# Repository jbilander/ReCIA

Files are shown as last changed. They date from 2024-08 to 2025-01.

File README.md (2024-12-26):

# ReCIA
A drop in replacement CIA (8520) for old Amiga Computers

This is WORK IN PROGRESS. If you generate gerbers and order PCBs from this source you are doing so completely at your own risk!.

Current design is based on an intel/altera 10 Max FPGA but this is mostly so we can signal tap and record how a real 8520 behaves.
The oscillator on board is 10 MHz and the PLL on the Max 10 can take this clock and make a perfect 28.375 MHz or a 28.636 MHz clock signal which will be nice to base the logic on instead of the E-CLK.

The final design will probably target a `LCMXO2-640HC-4SG48C` FPGA or a microcontroller such as `AVR128DA64` or a `RP2350`.

When the DIP-version is functional a PLCC-version (for big box Amigas) can be made.

***

<a href="images/ReCIA-Max10_pic1.png">
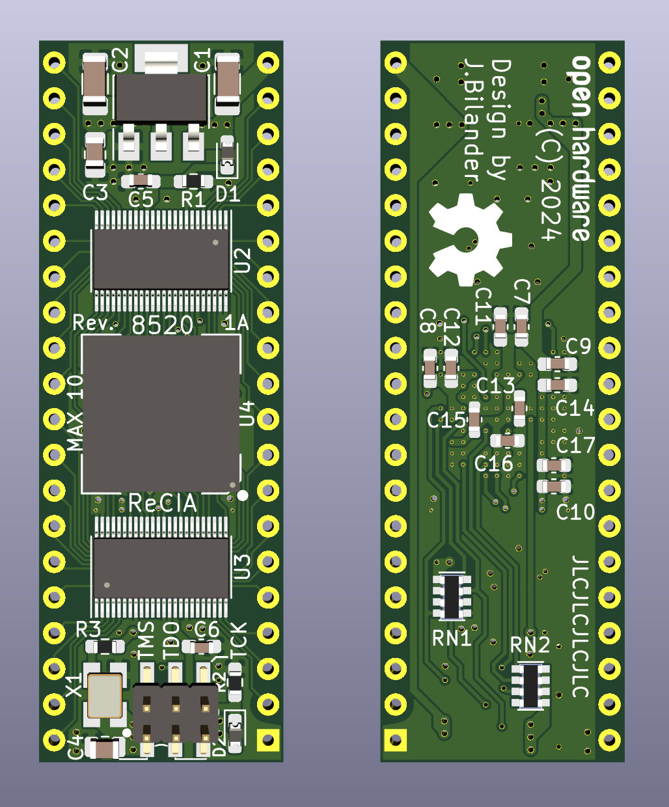
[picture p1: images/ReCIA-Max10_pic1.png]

</a>
<br />
<a href="images/ReCIA-Max10_pic2.jpg">
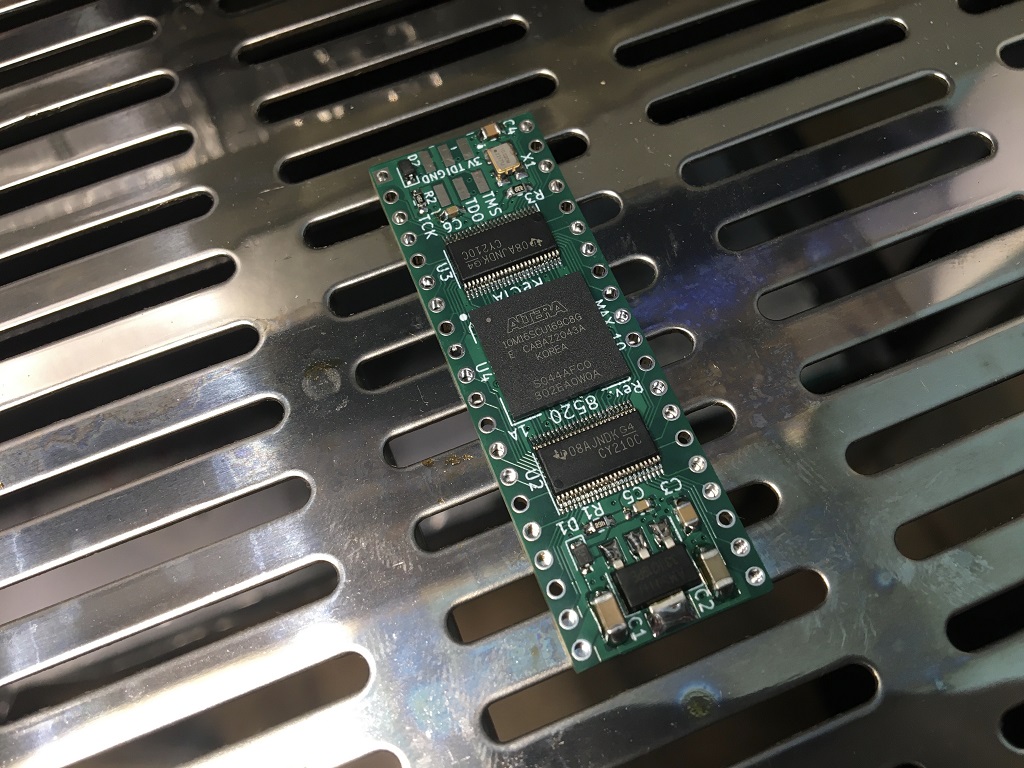
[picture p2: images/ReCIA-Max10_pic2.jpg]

</a>
<a href="images/ReCIA-Max10_pic3.jpg">
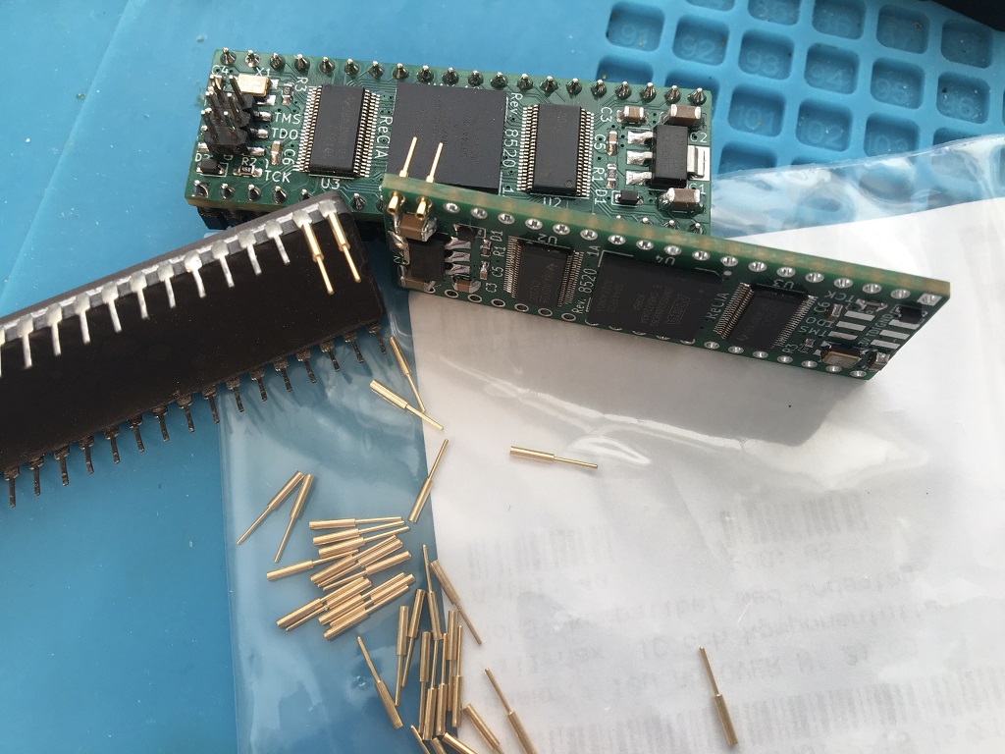
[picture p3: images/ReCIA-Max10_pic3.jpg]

</a>
<a href="images/ReCIA-Max10_pic4.jpg">
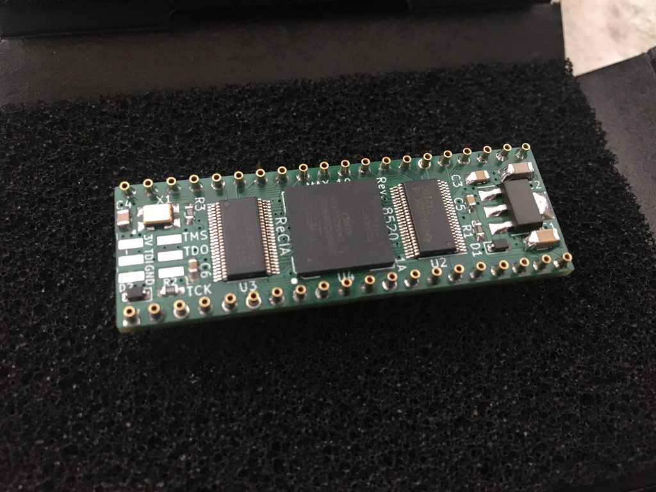
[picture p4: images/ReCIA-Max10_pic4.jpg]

</a>
<br />
<a href="images/ReCIA-Max10_pic5.jpg">
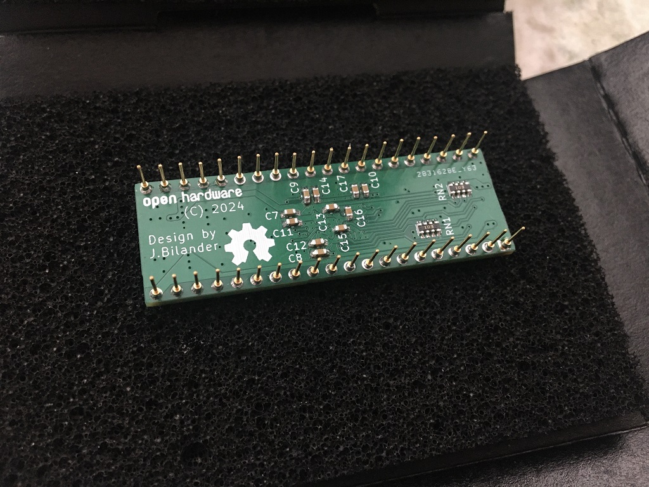
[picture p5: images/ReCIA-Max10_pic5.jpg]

</a>
<a href="images/ReCIA-Max10_pic6.jpg">
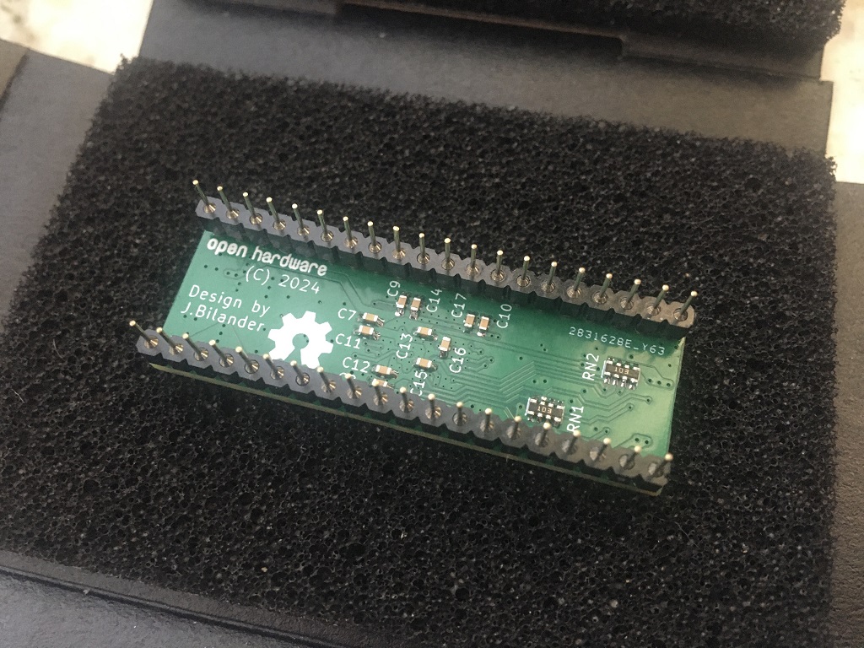
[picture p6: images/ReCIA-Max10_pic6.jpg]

</a>
<a href="images/ReCIA-Max10_pic7.jpg">
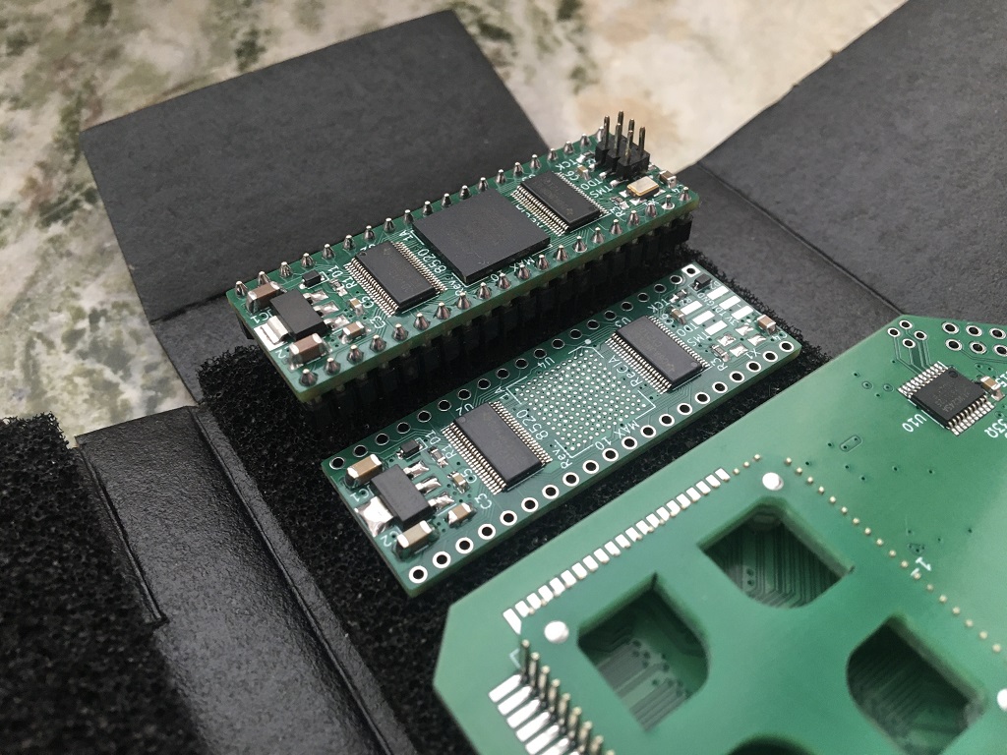
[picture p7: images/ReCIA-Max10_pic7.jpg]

</a>
<br />
<a href="images/ReCIA-Max10_pic8.jpg">
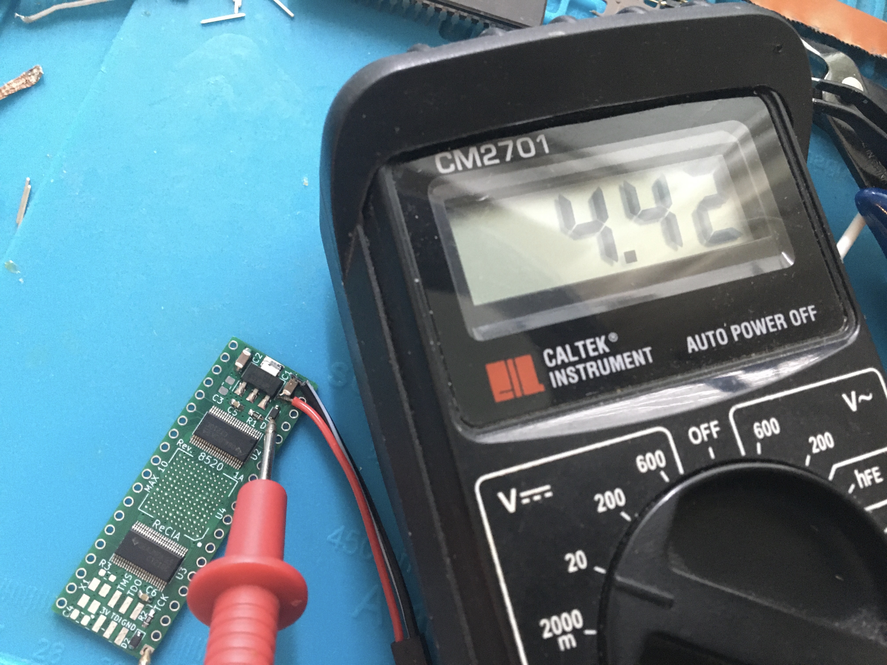
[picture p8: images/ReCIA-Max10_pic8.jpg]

</a>
<a href="images/ReCIA-Max10_pic9.jpg">
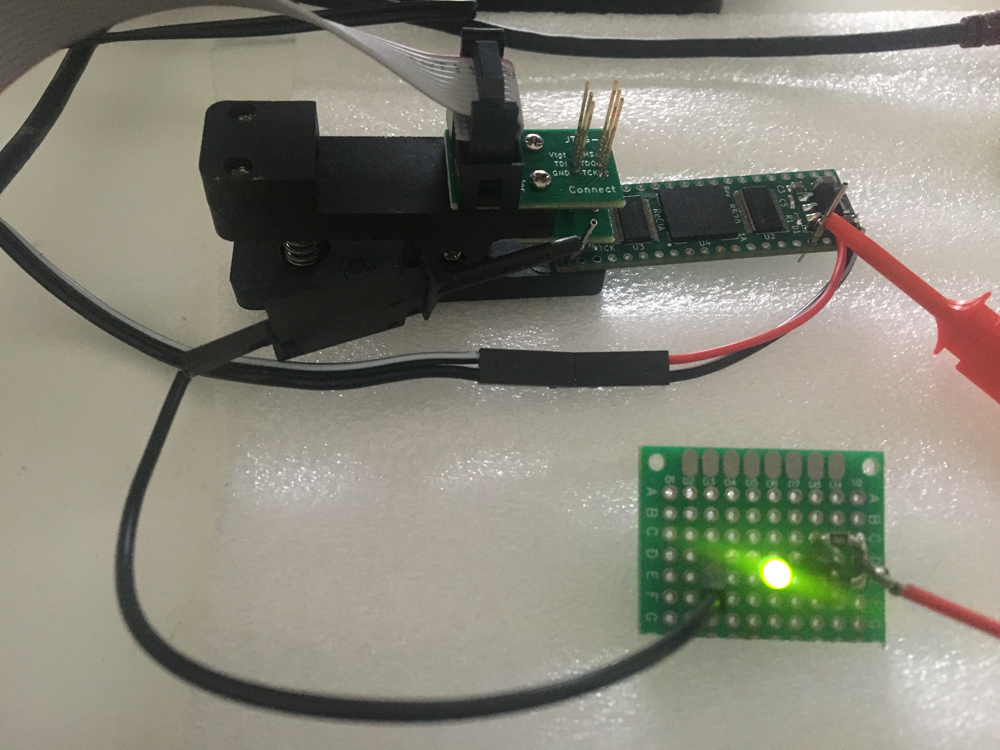
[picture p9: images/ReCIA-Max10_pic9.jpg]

</a>

***

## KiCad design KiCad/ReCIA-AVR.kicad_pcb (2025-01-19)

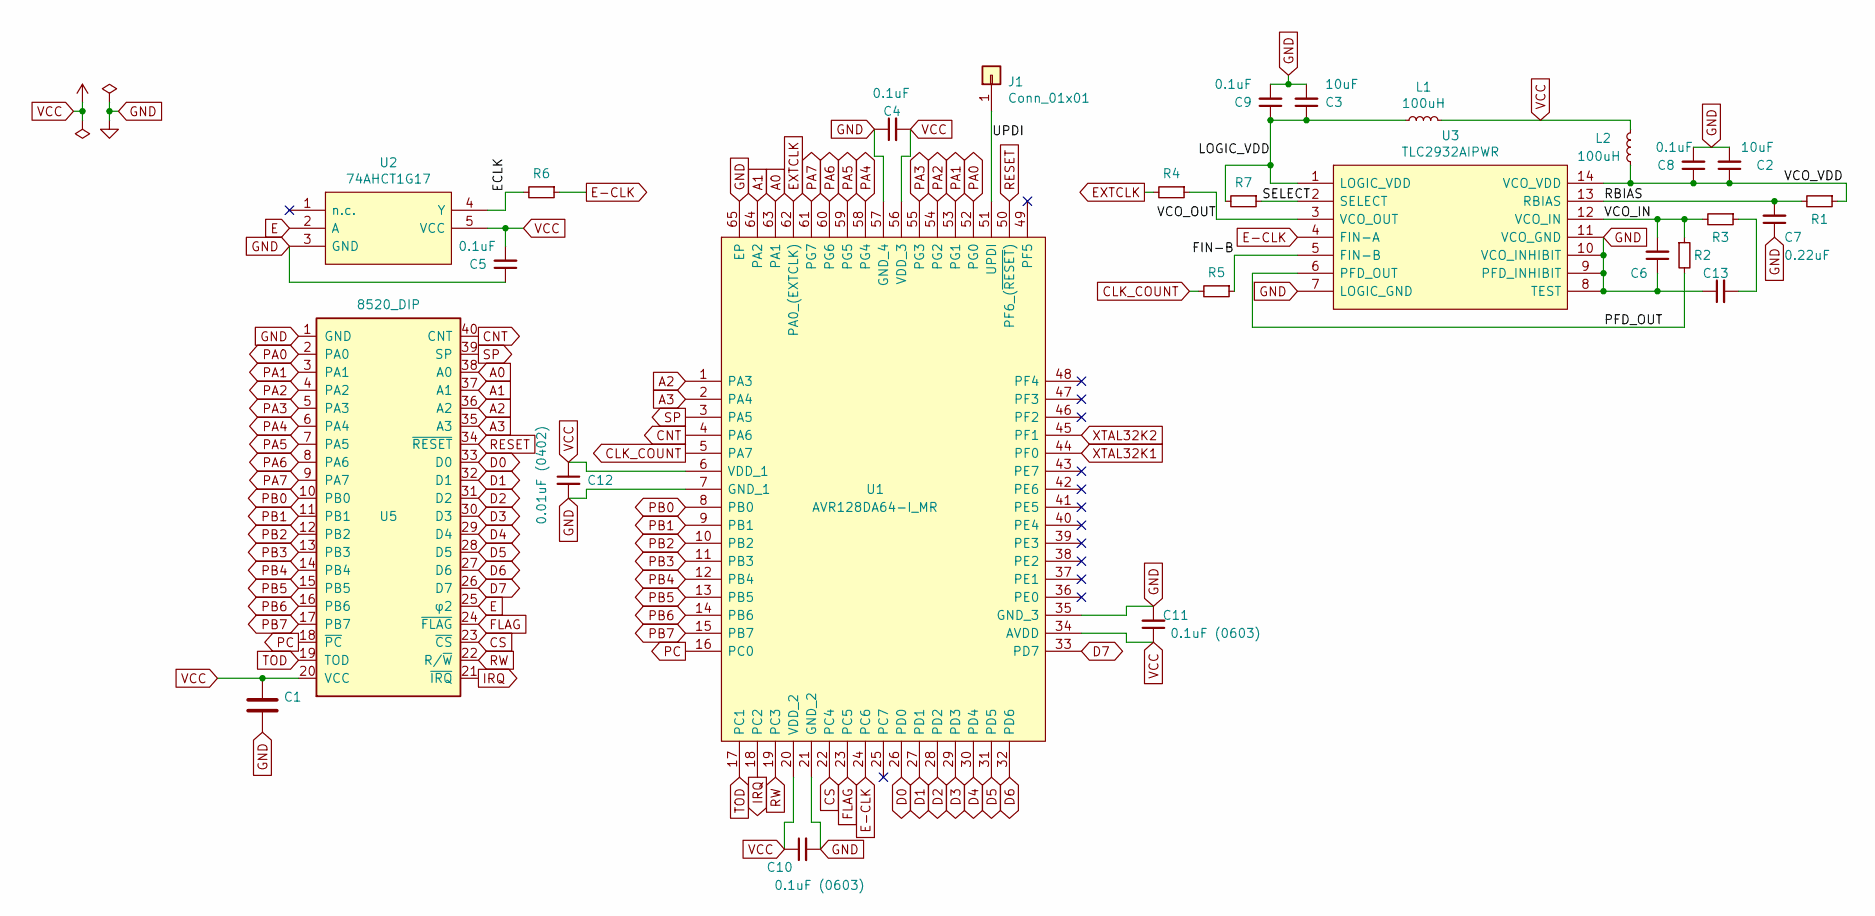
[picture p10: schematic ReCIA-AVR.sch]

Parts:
C1: C; C_1206_3216Metric_Pad1.33x1.80mm_HandSolder
C2, C3: 10uF; C_1206_3216Metric_Pad1.33x1.80mm_HandSolder
C4, C5, C6, C8, C9, C13: 0.1uF; C_0603_1608Metric_Pad1.08x0.95mm_HandSolder
C7: 0.22uF; C_0603_1608Metric_Pad1.08x0.95mm_HandSolder
C10, C11: 0.1uF (0603); C_0603_1608Metric_Pad1.08x0.95mm_HandSolder
C12: 0.01uF (0402); C_0402_1005Metric
J1: Conn_01x01; PinHeader_1x01_P2.54mm_Vertical
L1, L2: 100uH; L_0805_2012Metric_Pad1.15x1.40mm_HandSolder
R1: 3k3; R_0603_1608Metric_Pad0.98x0.95mm_HandSolder
R2, R3, R4, R5, R6: 33; R_0603_1608Metric_Pad0.98x0.95mm_HandSolder
R7: 10k; R_0603_1608Metric_Pad0.98x0.95mm_HandSolder
U1: AVR128DA64-I_MR; QFN-64-1EP_9x9mm_P0.5mm_EP7.15x7.15mm_ThermalVias
U2: 74AHCT1G17; SOT95P275X110-5N
U3: TLC2932AIPWR; TSSOP-14_4.4x5mm_P0.65mm
U5: 8520_DIP; DIP-40_W15.24mm

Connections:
/ECLK: R6.2, U2.4 (Y)
/FIN-B: R5.1, U3.5 (FIN-B)
/LOGIC_VDD: C3.1, C9.1, L1.1, R7.2, U3.1 (LOGIC_VDD)
/PFD_OUT: R2.2, U3.6 (PFD_OUT)
/RBIAS: C7.2, R1.2, U3.13 (RBIAS)
/SELECT: R7.1, U3.2 (SELECT)
/UPDI: J1.1, U1.51 (UPDI)
/VCO_IN: C6.2, R2.1, R3.2, U3.12 (VCO_IN)
/VCO_OUT: R4.1, U3.3 (VCO_OUT)
/VCO_VDD: C2.1, C8.1, L2.1, R1.1, U3.14 (VCO_VDD)
A0: U1.63 (PA1), U5.38 (A0)
A1: U1.64 (PA2), U5.37 (A1)
A2: U1.1 (PA3), U5.36 (A2)
A3: U1.2 (PA4), U5.35 (A3)
CLK_COUNT: R5.2, U1.5 (PA7)
CNT: U1.4 (PA6), U5.40 (CNT)
CS: U1.22 (PC4), U5.23 (~CS)
D0: U1.26 (PD0), U5.33 (D0)
D1: U1.27 (PD1), U5.32 (D1)
D2: U1.28 (PD2), U5.31 (D2)
D3: U1.29 (PD3), U5.30 (D3)
D4: U1.30 (PD4), U5.29 (D4)
D5: U1.31 (PD5), U5.28 (D5)
D6: U1.32 (PD6), U5.27 (D6)
D7: U1.33 (PD7), U5.26 (D7)
E: U2.2 (A), U5.25 (φ2)
E-CLK: R6.1, U1.24 (PC6), U3.4 (FIN-A)
EXTCLK: R4.2, U1.62 (PA0_(EXTCLK))
FLAG: U1.23 (PC5), U5.24 (~FLAG)
GND: C1.2, C2.2, C3.2, C4.1, C5.1, C6.1, C7.1, C8.2, C9.2, C10.2, C11.2, C12.2, C13.1, U1.7 (GND_1), U1.21 (GND_2), U1.35 (GND_3), U1.57 (GND_4), U1.65 (EP), U2.3 (GND), U3.7 (LOGIC_GND), U3.8 (TEST), U3.9 (PFD_INHIBIT), U3.10 (VCO_INHIBIT), U3.11 (VCO_GND), U5.1 (GND)
IRQ: U1.18 (PC2), U5.21 (~IRQ)
unnamed: C13.2, R3.1
PA0: U1.52 (PG0), U5.2 (PA0)
PA1: U1.53 (PG1), U5.3 (PA1)
PA2: U1.54 (PG2), U5.4 (PA2)
PA3: U1.55 (PG3), U5.5 (PA3)
PA4: U1.58 (PG4), U5.6 (PA4)
PA5: U1.59 (PG5), U5.7 (PA5)
PA6: U1.60 (PG6), U5.8 (PA6)
PA7: U1.61 (PG7), U5.9 (PA7)
PB0: U1.8 (PB0), U5.10 (PB0)
PB1: U1.9 (PB1), U5.11 (PB1)
PB2: U1.10 (PB2), U5.12 (PB2)
PB3: U1.11 (PB3), U5.13 (PB3)
PB4: U1.12 (PB4), U5.14 (PB4)
PB5: U1.13 (PB5), U5.15 (PB5)
PB6: U1.14 (PB6), U5.16 (PB6)
PB7: U1.15 (PB7), U5.17 (PB7)
PC: U1.16 (PC0), U5.18 (~PC)
RESET: U1.50 (PF6_(~RESET)), U5.34 (~RESET)
RW: U1.19 (PC3), U5.22 (R/~W)
SP: U1.3 (PA5), U5.39 (SP)
TOD: U1.17 (PC1), U5.19 (TOD)
VCC: C1.1, C4.2, C5.2, C10.1, C11.1, C12.1, L1.2, L2.2, U1.6 (VDD_1), U1.20 (VDD_2), U1.34 (AVDD), U1.56 (VDD_3), U2.5 (VCC), U5.20 (VCC)
XTAL32K1: U1.44 (PF0)
XTAL32K2: U1.45 (PF1)

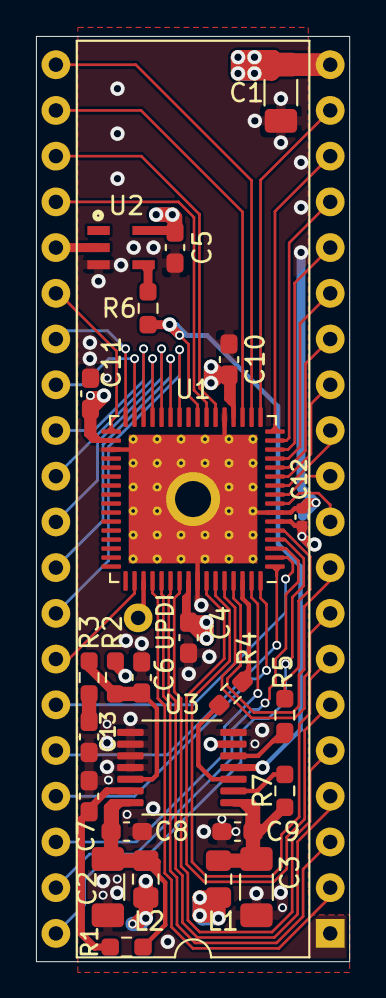
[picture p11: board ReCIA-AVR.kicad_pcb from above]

Board: 4 copper layers, 17.4 x 51.4 mm, 27 parts (0 on the bottom side), 54 nets.

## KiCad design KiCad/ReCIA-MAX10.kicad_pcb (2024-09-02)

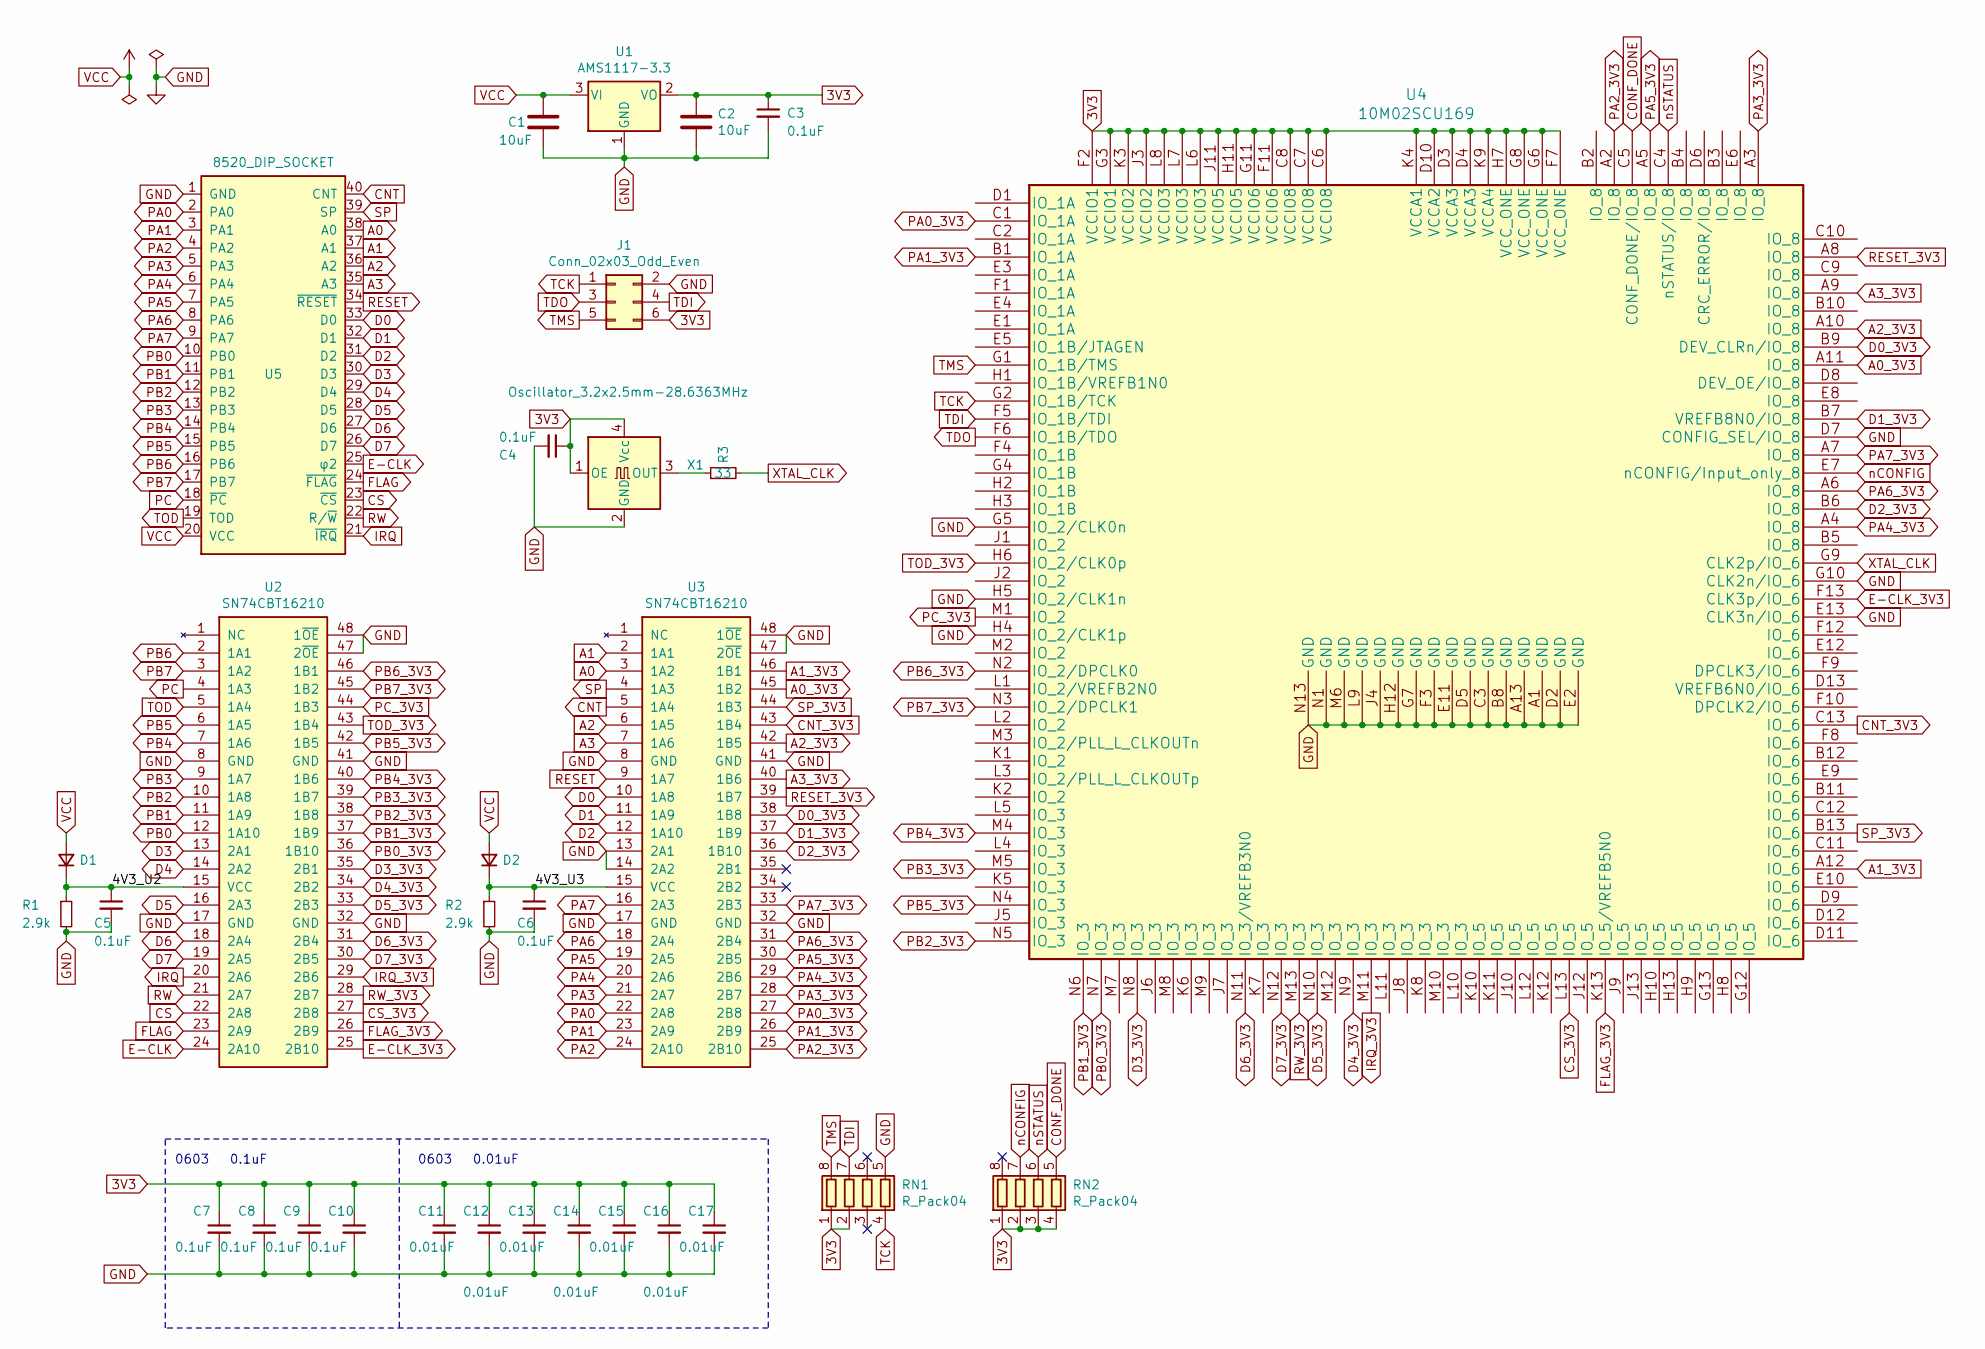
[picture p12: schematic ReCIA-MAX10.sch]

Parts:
C1, C2: 10uF; C_1206_3216Metric_Pad1.33x1.80mm_HandSolder
C3: 0.1uF; C_0805_2012Metric_Pad1.18x1.45mm_HandSolder
C4: 0.1uF; C_0805_2012Metric
C5, C6, C7, C8, C9: 0.1uF; C_0603_1608Metric_Pad1.08x0.95mm_HandSolder
C10: 0.1uF; C_0603_1608Metric
C11, C12, C13, C14, C15: 0.01uF; C_0603_1608Metric_Pad1.08x0.95mm_HandSolder
C16, C17: 0.01uF; C_0603_1608Metric
D1, D2: D_Small; D_0603_1608Metric_Pad1.05x0.95mm_HandSolder
J1: Conn_02x03_Odd_Even; PinHeader_2x03_P2.00mm_Vertical_SMD
R1, R2: 2.9k; R_0603_1608Metric_Pad0.98x0.95mm_HandSolder
R3: 33; R_0603_1608Metric_Pad0.98x0.95mm_HandSolder
RN1, RN2: R_Pack04; RESCAF80P320X160X60-8N
U1: AMS1117-3.3; SOT-223-3_TabPin2
U2, U3: SN74CBT16210; TSSOP-48_4.4x9.7mm_P0.4mm
U4: 10M02SCU169; BGA-169_11.0x11.0mm_Layout13x13_P0.8mm_Ball0.5mm_Pad0.35mm_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
U5: 8520_DIP_SOCKET; DIP-40_W15.24mm
X1: Oscillator_3.2x2.5mm-28.6363MHz; Oscillator_SMD_SeikoEpson_SG8002CE-4Pin_3.2x2.5mm

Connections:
3V3: C2.1, C3.1, C4.1, C7.1, C8.1, C9.1, C10.1, C11.1, C12.1, C13.1, C14.1, C15.1, C16.1, C17.1, J1.6, RN1.1 (R1.1), RN1.2 (R2.1), RN2.1 (R1.1), RN2.2 (R2.1), RN2.3 (R3.1), RN2.4 (R4.1), U1.2 (VO), U4.C6 (VCCIO8), U4.C7 (VCCIO8), U4.C8 (VCCIO8), U4.D3 (VCCA3), U4.D4 (VCCA3), U4.D10 (VCCA2), U4.F2 (VCCIO1), U4.F7 (VCC_ONE), U4.F11 (VCCIO6), U4.G3 (VCCIO1), U4.G6 (VCC_ONE), U4.G8 (VCC_ONE), U4.G11 (VCCIO6), U4.H7 (VCC_ONE), U4.H11 (VCCIO5), U4.J3 (VCCIO2), U4.J11 (VCCIO5), U4.K3 (VCCIO2), U4.K4 (VCCA1), U4.K9 (VCCA4), U4.L6 (VCCIO3), U4.L7 (VCCIO3), U4.L8 (VCCIO3), X1.1 (OE), X1.4 (Vcc)
/4V3_U2: C5.1, D1.1 (K), R1.1, U2.15 (VCC)
/4V3_U3: C6.1, D2.1 (K), R2.1, U3.15 (VCC)
A0: U3.3 (1A2), U5.38 (A0)
A0_3V3: U3.45 (1B2), U4.A11 (IO_8)
A1: U3.2 (1A1), U5.37 (A1)
A1_3V3: U3.46 (1B1), U4.A12 (IO_6)
A2: U3.6 (1A5), U5.36 (A2)
A2_3V3: U3.42 (1B5), U4.A10 (IO_8)
A3: U3.7 (1A6), U5.35 (A3)
A3_3V3: U3.40 (1B6), U4.A9 (IO_8)
CNT: U3.5 (1A4), U5.40 (CNT)
CNT_3V3: U3.43 (1B4), U4.C13 (IO_6)
CONF_DONE: RN2.5 (R4.2), U4.C5 (CONF_DONE/IO_8)
CS: U2.22 (2A8), U5.23 (~CS)
CS_3V3: U2.27 (2B8), U4.L13 (IO_5)
D0: U3.10 (1A8), U5.33 (D0)
D0_3V3: U3.38 (1B8), U4.B9 (DEV_CLRn/IO_8)
D1: U3.11 (1A9), U5.32 (D1)
D1_3V3: U3.37 (1B9), U4.B7 (VREFB8N0/IO_8)
D2: U3.12 (1A10), U5.31 (D2)
D2_3V3: U3.36 (1B10), U4.B6 (IO_8)
D3: U2.13 (2A1), U5.30 (D3)
D3_3V3: U2.35 (2B1), U4.N8 (IO_3)
D4: U2.14 (2A2), U5.29 (D4)
D4_3V3: U2.34 (2B2), U4.N9 (IO_3)
D5: U2.16 (2A3), U5.28 (D5)
D5_3V3: U2.33 (2B3), U4.N10 (IO_3)
D6: U2.18 (2A4), U5.27 (D6)
D6_3V3: U2.31 (2B4), U4.N11 (IO_3/VREFB3N0)
D7: U2.19 (2A5), U5.26 (D7)
D7_3V3: U2.30 (2B5), U4.N12 (IO_3)
E-CLK: U2.24 (2A10), U5.25 (φ2)
E-CLK_3V3: U2.25 (2B10), U4.F13 (CLK3p/IO_6)
FLAG: U2.23 (2A9), U5.24 (~FLAG)
FLAG_3V3: U2.26 (2B9), U4.K13 (IO_5/VREFB5N0)
GND: C1.2, C2.2, C3.2, C4.2, C5.2, C6.2, C7.2, C8.2, C9.2, C10.2, C11.2, C12.2, C13.2, C14.2, C15.2, C16.2, C17.2, J1.2, R1.2, R2.2, RN1.5 (R4.2), U1.1 (GND), U2.8 (GND), U2.17 (GND), U2.32 (GND), U2.41 (GND), U2.47 (2~OE), U2.48 (1~OE), U3.8 (GND), U3.13 (2A1), U3.14 (2A2), U3.17 (GND), U3.32 (GND), U3.41 (GND), U3.47 (2~OE), U3.48 (1~OE), U4.A1 (GND), U4.A13 (GND), U4.B8 (GND), U4.C3 (GND), U4.D2 (GND), U4.D5 (GND), U4.D7 (CONFIG_SEL/IO_8), U4.E2 (GND), U4.E11 (GND), U4.E13 (CLK3n/IO_6), U4.F3 (GND), U4.G5 (IO_2/CLK0n), U4.G7 (GND), U4.G10 (CLK2n/IO_6), U4.H4 (IO_2/CLK1p), U4.H5 (IO_2/CLK1n), U4.H12 (GND), U4.J4 (GND), U4.L9 (GND), U4.M6 (GND), U4.N1 (GND), U4.N13 (GND), U5.1 (GND), X1.2 (GND)
IRQ: U2.20 (2A6), U5.21 (~IRQ)
IRQ_3V3: U2.29 (2B6), U4.M11 (IO_3)
unnamed: R3.1, X1.3 (OUT)
PA0: U3.22 (2A8), U5.2 (PA0)
PA0_3V3: U3.27 (2B8), U4.C1 (IO_1A)
PA1: U3.23 (2A9), U5.3 (PA1)
PA1_3V3: U3.26 (2B9), U4.B1 (IO_1A)
PA2: U3.24 (2A10), U5.4 (PA2)
PA2_3V3: U3.25 (2B10), U4.A2 (IO_8)
PA3: U3.21 (2A7), U5.5 (PA3)
PA3_3V3: U3.28 (2B7), U4.A3 (IO_8)
PA4: U3.20 (2A6), U5.6 (PA4)
PA4_3V3: U3.29 (2B6), U4.A4 (IO_8)
PA5: U3.19 (2A5), U5.7 (PA5)
PA5_3V3: U3.30 (2B5), U4.A5 (IO_8)
PA6: U3.18 (2A4), U5.8 (PA6)
PA6_3V3: U3.31 (2B4), U4.A6 (IO_8)
PA7: U3.16 (2A3), U5.9 (PA7)
PA7_3V3: U3.33 (2B3), U4.A7 (IO_8)
PB0: U2.12 (1A10), U5.10 (PB0)
PB0_3V3: U2.36 (1B10), U4.N7 (IO_3)
PB1: U2.11 (1A9), U5.11 (PB1)
PB1_3V3: U2.37 (1B9), U4.N6 (IO_3)
PB2: U2.10 (1A8), U5.12 (PB2)
PB2_3V3: U2.38 (1B8), U4.N5 (IO_3)
PB3: U2.9 (1A7), U5.13 (PB3)
PB3_3V3: U2.39 (1B7), U4.M5 (IO_3)
PB4: U2.7 (1A6), U5.14 (PB4)
PB4_3V3: U2.40 (1B6), U4.M4 (IO_3)
PB5: U2.6 (1A5), U5.15 (PB5)
PB5_3V3: U2.42 (1B5), U4.N4 (IO_3)
PB6: U2.2 (1A1), U5.16 (PB6)
PB6_3V3: U2.46 (1B1), U4.N2 (IO_2/DPCLK0)
PB7: U2.3 (1A2), U5.17 (PB7)
PB7_3V3: U2.45 (1B2), U4.N3 (IO_2/DPCLK1)
PC: U2.4 (1A3), U5.18 (~PC)
PC_3V3: U2.44 (1B3), U4.M1 (IO_2)
RESET: U3.9 (1A7), U5.34 (~RESET)
RESET_3V3: U3.39 (1B7), U4.A8 (IO_8)
RW: U2.21 (2A7), U5.22 (R/~W)
RW_3V3: U2.28 (2B7), U4.M13 (IO_3)
SP: U3.4 (1A3), U5.39 (SP)
SP_3V3: U3.44 (1B3), U4.B13 (IO_6)
TCK: J1.1, RN1.4 (R4.1), U4.G2 (IO_1B/TCK)
TDI: J1.4, RN1.7 (R2.2), U4.F5 (IO_1B/TDI)
TDO: J1.3, U4.F6 (IO_1B/TDO)
TMS: J1.5, RN1.8 (R1.2), U4.G1 (IO_1B/TMS)
TOD: U2.5 (1A4), U5.19 (TOD)
TOD_3V3: U2.43 (1B4), U4.H6 (IO_2/CLK0p)
VCC: C1.1, D1.2 (A), D2.2 (A), U1.3 (VI), U5.20 (VCC)
XTAL_CLK: R3.2, U4.G9 (CLK2p/IO_6)
nCONFIG: RN2.7 (R2.2), U4.E7 (nCONFIG/Input_only_8)
nSTATUS: RN2.6 (R3.2), U4.C4 (nSTATUS/IO_8)

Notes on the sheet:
0603 0.1uF
0603 0.01uF

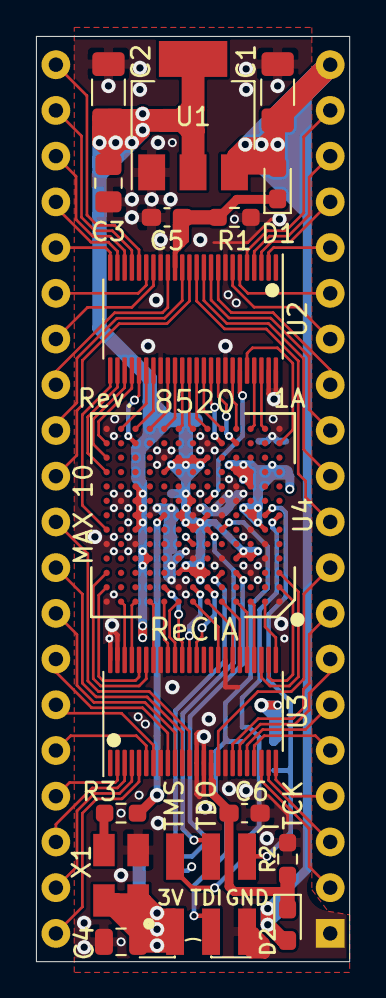
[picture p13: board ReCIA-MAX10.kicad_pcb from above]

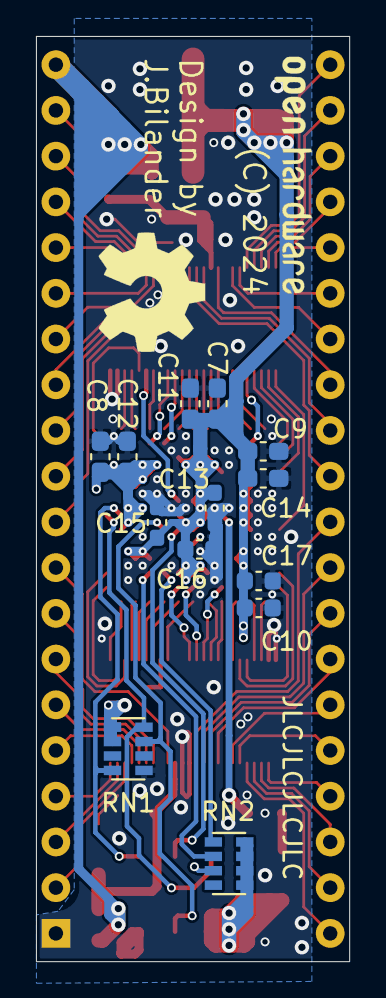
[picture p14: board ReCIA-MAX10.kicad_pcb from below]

Board: 4 copper layers, 17.4 x 51.4 mm, 31 parts (13 on the bottom side), 90 nets.

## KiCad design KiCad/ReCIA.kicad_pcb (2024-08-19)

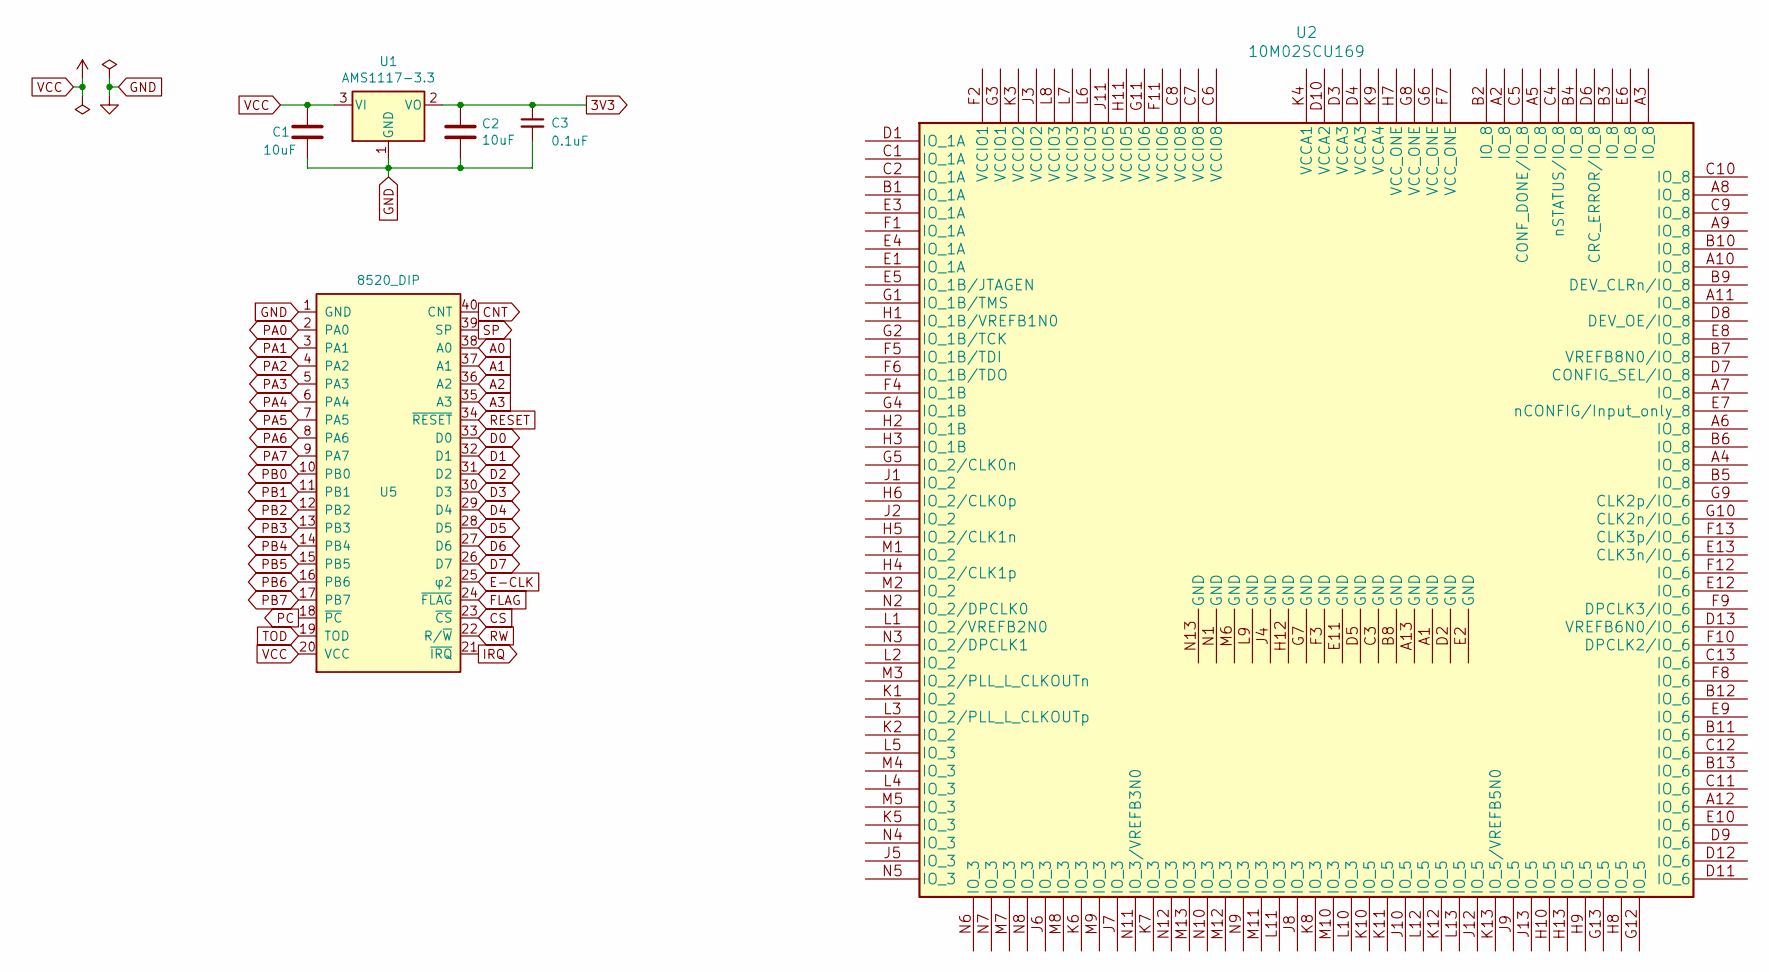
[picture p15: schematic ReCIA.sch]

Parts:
C1, C2: 10uF; C_1206_3216Metric_Pad1.33x1.80mm_HandSolder
C3: 0.1uF; C_0805_2012Metric_Pad1.18x1.45mm_HandSolder
U1: AMS1117-3.3; SOT-223-3_TabPin2
U2: 10M02SCU169; BGA-169_11.0x11.0mm_Layout13x13_P0.8mm_Ball0.5mm_Pad0.35mm_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
U5: 8520_DIP; DIP-40_W15.24mm

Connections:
3V3: C2.1, C3.1, U1.2 (VO)
A0: U5.38 (A0)
A1: U5.37 (A1)
A2: U5.36 (A2)
A3: U5.35 (A3)
CNT: U5.40 (CNT)
CS: U5.23 (~CS)
D0: U5.33 (D0)
D1: U5.32 (D1)
D2: U5.31 (D2)
D3: U5.30 (D3)
D4: U5.29 (D4)
D5: U5.28 (D5)
D6: U5.27 (D6)
D7: U5.26 (D7)
E-CLK: U5.25 (φ2)
FLAG: U5.24 (~FLAG)
GND: C1.2, C2.2, C3.2, U1.1 (GND), U5.1 (GND)
IRQ: U5.21 (~IRQ)
PA0: U5.2 (PA0)
PA1: U5.3 (PA1)
PA2: U5.4 (PA2)
PA3: U5.5 (PA3)
PA4: U5.6 (PA4)
PA5: U5.7 (PA5)
PA6: U5.8 (PA6)
PA7: U5.9 (PA7)
PB0: U5.10 (PB0)
PB1: U5.11 (PB1)
PB2: U5.12 (PB2)
PB3: U5.13 (PB3)
PB4: U5.14 (PB4)
PB5: U5.15 (PB5)
PB6: U5.16 (PB6)
PB7: U5.17 (PB7)
PC: U5.18 (~PC)
RESET: U5.34 (~RESET)
RW: U5.22 (R/~W)
SP: U5.39 (SP)
TOD: U5.19 (TOD)
VCC: C1.1, U1.3 (VI), U5.20 (VCC)

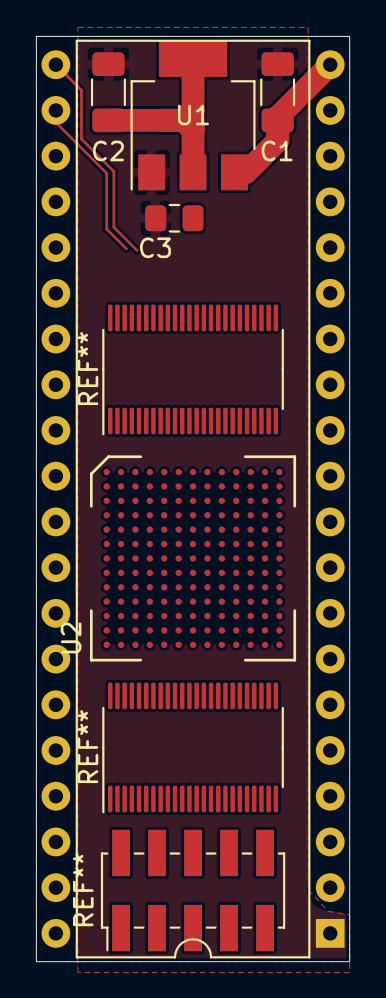
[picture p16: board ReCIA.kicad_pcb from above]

Board: 4 copper layers, 17.4 x 51.4 mm, 6 parts (0 on the bottom side), 3 nets.

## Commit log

2024-08-15 Add KiCad files
    [ReCIA.kicad_pcb, ReCIA.sch]
2024-08-15 Changed to four layers and fixed clearance and default settings for traces and vias etc
    [ReCIA.kicad_pcb]
2024-08-15 Add nets
    [ReCIA.kicad_pcb, ReCIA.sch]
2024-08-16 Added a 3.3V LDO Voltage Regulator
    [ReCIA.kicad_pcb, ReCIA.sch]
2024-08-19 Add footprint
2024-08-19 Add 10 Max FPGA
    [ReCIA.kicad_pcb, ReCIA.sch]
2024-08-21 Add KiCad files for AVR-version
    [ReCIA-AVR.kicad_pcb, ReCIA-AVR.sch]
2024-08-21 Add QFN-80 footprint
2024-08-21 Add KiCad files for Max10 version
    [ReCIA-MAX10.kicad_pcb, ReCIA-MAX10.sch]
2024-08-21 Add KiCad lib for Max10 version
2024-08-26 Add FET bus-switch level shifters SN74CBT16210
    [ReCIA-MAX10.kicad_pcb, ReCIA-MAX10.sch]
2024-08-26 Add JTAG-header
    [ReCIA-MAX10.kicad_pcb, ReCIA-MAX10.sch]
2024-08-27 more routing and pin assignment
    [ReCIA-MAX10.kicad_pcb, ReCIA-MAX10.sch]
2024-08-27 routing JTAG plus more routing of power to BGA chip
    [ReCIA-MAX10.kicad_pcb, ReCIA-MAX10.sch]
2024-08-27 add XTAL to design
    [ReCIA-MAX10.kicad_pcb, ReCIA-MAX10.sch]
2024-08-27 add XTAL step file to 3D Setting for X1
    [ReCIA-MAX10.kicad_pcb]
2024-08-27 add 15 mil trace
2024-08-27 re-routed XTAL trace with 15 mil trace
    [ReCIA-MAX10.kicad_pcb]
2024-08-27 more routing, pin assignments and silkscreen fixes
    [ReCIA-MAX10.kicad_pcb, ReCIA-MAX10.sch]
2024-08-28 more pin assignments and routing
    [ReCIA-MAX10.kicad_pcb, ReCIA-MAX10.sch]
2024-08-28 more power routing, vias and silkscreen fixes
    [ReCIA-MAX10.kicad_pcb]
2024-08-28 Changed to minimum width to 0.14 mm for front F.Cu zone and solid pad connection to zone for BGA-footprint.
    [ReCIA-MAX10.kicad_pcb]
2024-08-28 Silkscreen fixes, add dot indicator for pin 1 on U2,U3,U4
    [ReCIA-MAX10.kicad_pcb]
2024-08-28 Add pin assignment and routing for D0,D1,D2 to the FPGA
    [ReCIA-MAX10.kicad_pcb, ReCIA-MAX10.sch]
2024-08-29 Add decoupling caps for FPGA-chip
    [ReCIA-MAX10.kicad_pcb, ReCIA-MAX10.sch]
2024-08-30 Add more decoupling caps for FPGA-chip
    [ReCIA-MAX10.kicad_pcb, ReCIA-MAX10.sch]
2024-08-30 Assign GND to CONFIG_SEL pad
    [ReCIA-MAX10.kicad_pcb, ReCIA-MAX10.sch]
2024-08-30 Add nCONFIG signal
    [ReCIA-MAX10.kicad_pcb, ReCIA-MAX10.sch]
2024-08-30 Add nSTATUS signal
    [ReCIA-MAX10.kicad_pcb, ReCIA-MAX10.sch]
2024-08-30 Add CONF_DONE signal
    [ReCIA-MAX10.kicad_pcb, ReCIA-MAX10.sch]
2024-08-31 add 3d model for resistor pack
2024-08-31 add footprint for resistor pack
2024-08-31 Add 10k resistor pack RN1 and assign pull-ups for TMS, TDI and pull-down for TCK
    [ReCIA-MAX10.kicad_pcb, ReCIA-MAX10.sch]
2024-08-31 Add 10k resistor pack RN2 with pull-ups for CONF_DONE, nSTATUS, nCONFIG
    [ReCIA-MAX10.kicad_pcb, ReCIA-MAX10.sch]
2024-09-01 small fix 3V3-routing
    [ReCIA-MAX10.kicad_pcb]
2024-09-02 Assign H4,H5 pad to GND
    [ReCIA-MAX10.kicad_pcb, ReCIA-MAX10.sch]
2024-09-02 Add silkscreen texts
    [ReCIA-MAX10.kicad_pcb]
2024-09-02 corrected smalles via size to 0.45mm/0.2mm
    [ReCIA-MAX10.kicad_pcb]
2024-12-29 Pin assignment of A0-A3, SP, CNT signals for the AVR-version and more routing done
    [ReCIA-AVR.kicad_pcb, ReCIA-AVR.sch]
2025-01-05 Add a 74AHCT1G17 - Single Schmitt trigger buffer for the E-CLK on the AVR version
    [ReCIA-AVR.kicad_pcb, ReCIA-AVR.sch]
2025-01-05 Add decoupling cap for 74AHCT1G17 on the AVR version
    [ReCIA-AVR.kicad_pcb, ReCIA-AVR.sch]
2025-01-05 Add a 33 Ohm damping resistor on the E-CLK buffer out line
    [ReCIA-AVR.kicad_pcb, ReCIA-AVR.sch]
2025-01-05 Add TLC2932AIPWR to the AVR version
    [ReCIA-AVR.kicad_pcb, ReCIA-AVR.sch]
2025-01-05 Add 10uF 1206 capacitor on VCC input for the AVR version
    [ReCIA-AVR.kicad_pcb, ReCIA-AVR.sch]
2025-01-12 Fixed placement of PLL-chip and added inductor and caps for power supply pins Logic VDD and VCO VDD for the AVR-version
    [ReCIA-AVR.kicad_pcb, ReCIA-AVR.sch]
2025-01-12 Add 33 Ohm damping resistor on EXTCLK-line
    [ReCIA-AVR.kicad_pcb, ReCIA-AVR.sch]
2025-01-12 Add net and resistor between PDF_OUT and VCO_IN for the AVR-version
    [ReCIA-AVR.kicad_pcb, ReCIA-AVR.sch]
2025-01-12 Add resistor and net for PLL FIN-B clk-count input signal from AVR pin 5 (PA7)
    [ReCIA-AVR.kicad_pcb, ReCIA-AVR.sch]
2025-01-12 Add 0.4 mm track width
    [ReCIA-AVR.kicad_pcb]
2025-01-12 Add pull-up resistor on SELECT-line and more placement and routing fixes
    [ReCIA-AVR.kicad_pcb, ReCIA-AVR.sch]
2025-01-14 Add 3.3k resistor and 0.22uF cap for the RBIAS-pin on the PLL
    [ReCIA-AVR.kicad_pcb, ReCIA-AVR.sch]
2025-01-14 Add cap for the VCO_IN-pin on the PLL
    [ReCIA-AVR.kicad_pcb, ReCIA-AVR.sch]
2025-01-16 Change from 0805 to 1206 size on C2 and C3
    [ReCIA-AVR.kicad_pcb, ReCIA-AVR.sch]
2025-01-16 Add resistor and cap on VCO_IN line
    [ReCIA-AVR.kicad_pcb, ReCIA-AVR.sch]
2025-01-17 Fixed caps and resistor references enumeration, more routing and small fixes positioning vias
    [ReCIA-AVR.kicad_pcb, ReCIA-AVR.sch]
2025-01-18 corrected C8,C9 to 0.1uF
    [ReCIA-AVR.kicad_pcb, ReCIA-AVR.sch]
2025-01-19 Add UPDI pin-header
    [ReCIA-AVR.kicad_pcb, ReCIA-AVR.sch]
2025-01-19 Add annotation UPDI header
    [ReCIA-AVR.kicad_pcb, ReCIA-AVR.sch]

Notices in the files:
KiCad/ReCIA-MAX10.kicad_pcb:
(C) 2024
